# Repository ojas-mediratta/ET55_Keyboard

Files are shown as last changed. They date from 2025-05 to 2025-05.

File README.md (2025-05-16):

# ET55

## Overview

**ET55** is a 55‑key, hand‑wired mechanical keyboard created as the capstone project for **ECE 4180 – Embedded Systems Design** at Georgia Tech.  The goal was to design, fabricate, and program an ultra‑compact board that captures the feel of vintage IBM Model F layouts while showcasing modern embedded techniques—QMK firmware, USB‑C connectivity, an OLED status screen, and a rotary‑encoder volume knob.  All design files (schematic, PCB, plate, case, and firmware) are open‑sourced for anyone who wants to build or remix the board.

---

## Hardware

| Sub‑system | Details |
| --- | --- |
| **MCU** | Arduino Pro Micro / Bit‑C (ATmega32U4) with USB‑C connector |
| **Switch matrix**  | 55 MX‑compatible switches • Diode‑protected (COL2ROW) • NKRO enabled |
| **Keycaps** | Generic White on Black Keycaps |
| **Rotary encoder** | EC11 w/ integrated push‑button (used for volume + OLED mode cycling) |
| **OLED display** | 128×32 px SSD1306 module (I²C) for animations & system info |
| **Passives** | 1N4148 diodes (55×) • Reset capacitor & pull‑ups for I²C |
| **Power / I/O** | USB‑C for 5 V power & data |
| **Enclosure** | 3‑D printed case and switch plate (files included) |
| **Optional** | Surface‑mount ATmega32U4 variant for a future all‑in‑one PCB |

---

## Libraries & Code

ET55 runs stock **QMK** firmware (no custom forks), keeping the learning curve gentle for new contributors.

```bash
# Build the default keymap
qmk compile -kb et55 -km default

# Flash over USB (Pro Micro)
qmk flash -kb et55 -km default
```

* **Layers:** Base, Symbols, Nav, Function (configurable in `keymap.c`).
* **Encoder:** Volume up/down; press to cycle OLED screens.
* **OLED:** Bongo‑Cat animation + layer/status text (defined in `oled.c`).
* **Rules:** `rules.mk` enables LUFA, NKRO, OLED\_DRIVER, and ENCODER.

Feel free to fork and add combos, tap‑dance, or VIA support.

---

## Skills & Iteration

* **Schematic & PCB design** in KiCad; learned best‑practice matrix wiring and USB‑C routing.
* **Rapid prototyping:** 3‑D printed case revisions and laser‑cut plates ensured proper switch alignment before final print.
* **Hand‑wiring:** Applied heat‑shrink‑wrapped bus wires and diode‑legs to minimize shorts.
* **Firmware workflow:** QMK Configurator → local keymap → USB flashing & live debugging.
* **Peripheral integration:** Brought up I²C OLED on shared MCU pins, wrote basic frame‑buffer animations.
* **Documentation:** Maintained step‑by‑step build guide, BOM, and open‑sourced design files.

---

## Challenges

* **Tight matrix routing**—fitting 55 switches + diodes on a Pro Micro footprint required creative wire‑folds.
* **OLED noise**—solved flicker by adding 4.7 kΩ I²C pull‑ups and shielding SDA/SCL runs.
* **Encoder clearance**—first case revision fouled on encoder shaft; increased bezel height by 1 mm.
---

## Resources

* [QMK Docs](https://docs.qmk.fm/) – firmware reference & tutorials
* [nullbits Bit‑C](https://nullbits.co/bitc) – USB‑C Pro Micro replacement board
* [Hand‑Wired Guide](https://beta.docs.qmk.fm/tutorial/newbs_handwire) – official QMK hand‑wiring tutorial
* CAD, PCB, and firmware files are located in their respective folders in this repository—feel free to fork and improve.
---
## Photos and Videos

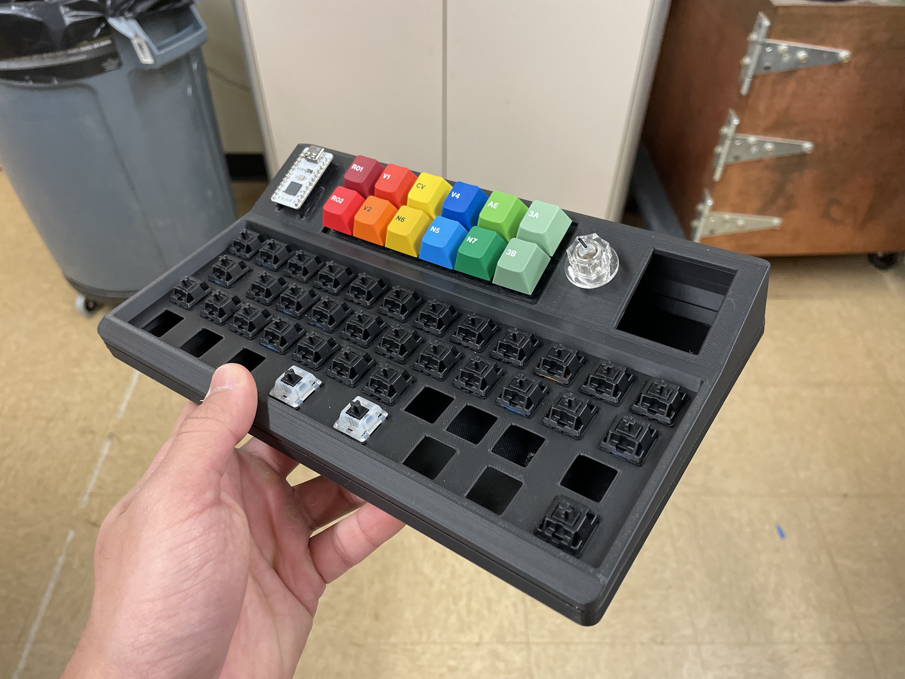
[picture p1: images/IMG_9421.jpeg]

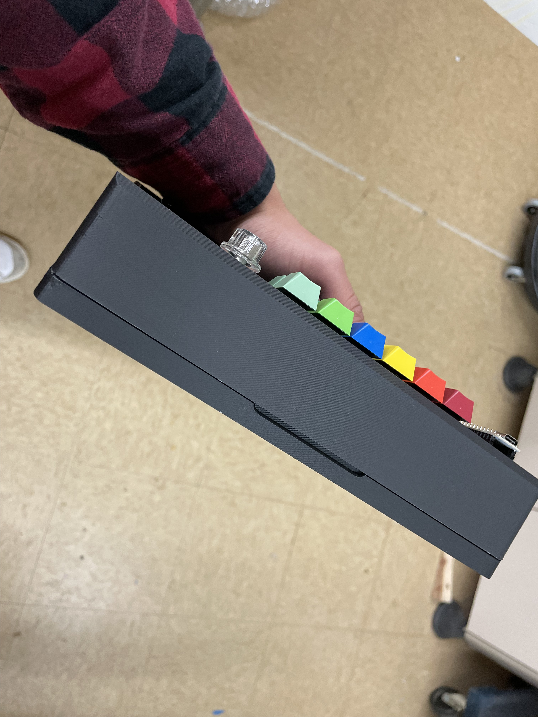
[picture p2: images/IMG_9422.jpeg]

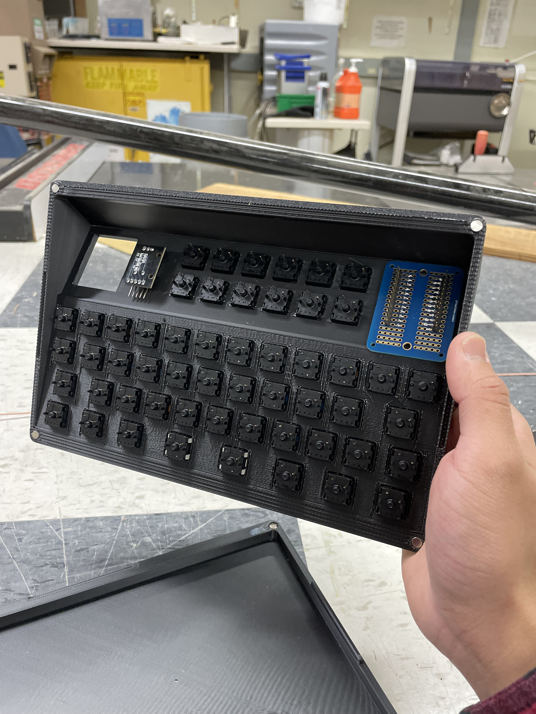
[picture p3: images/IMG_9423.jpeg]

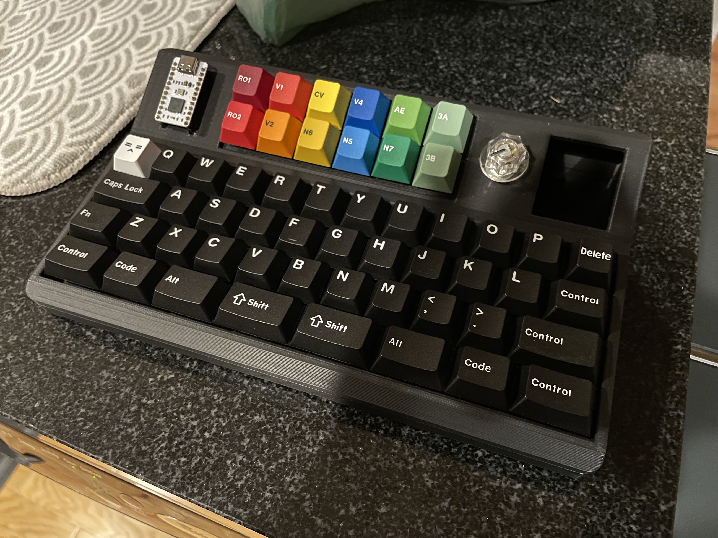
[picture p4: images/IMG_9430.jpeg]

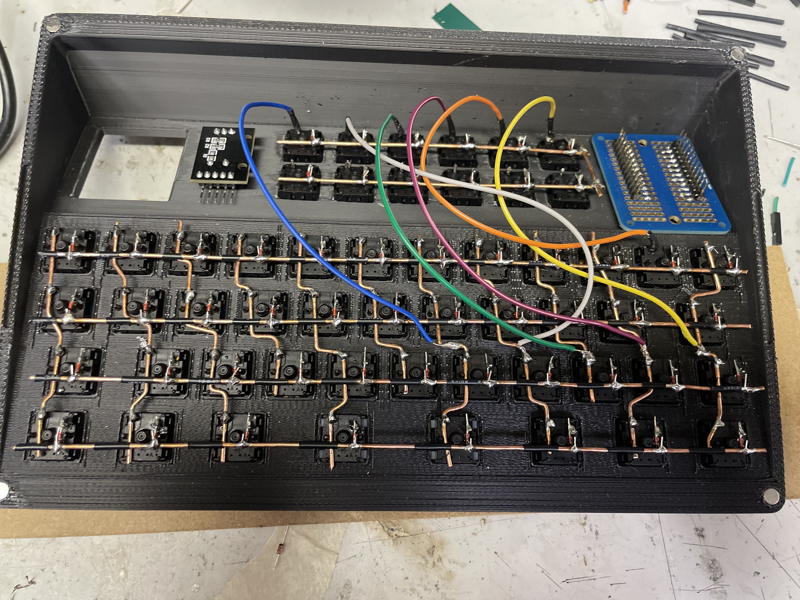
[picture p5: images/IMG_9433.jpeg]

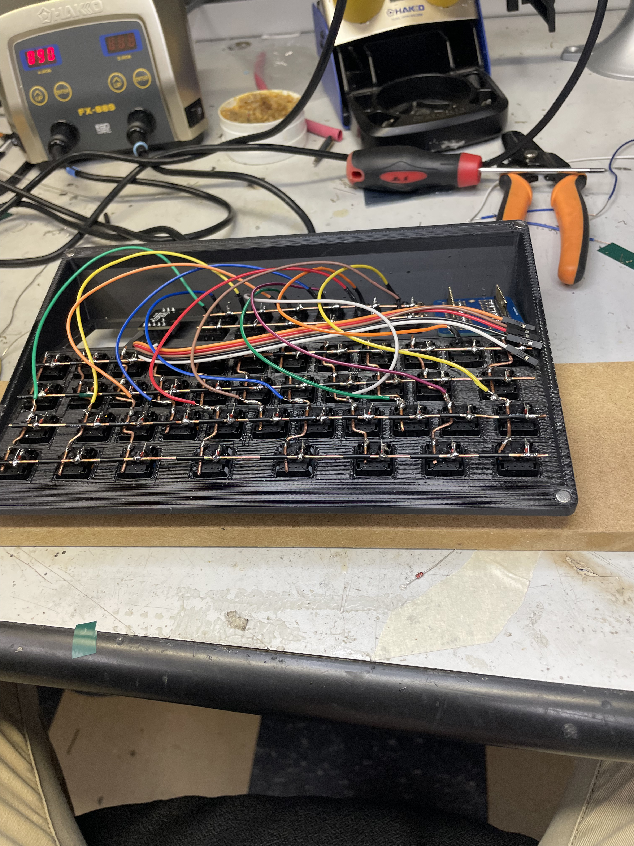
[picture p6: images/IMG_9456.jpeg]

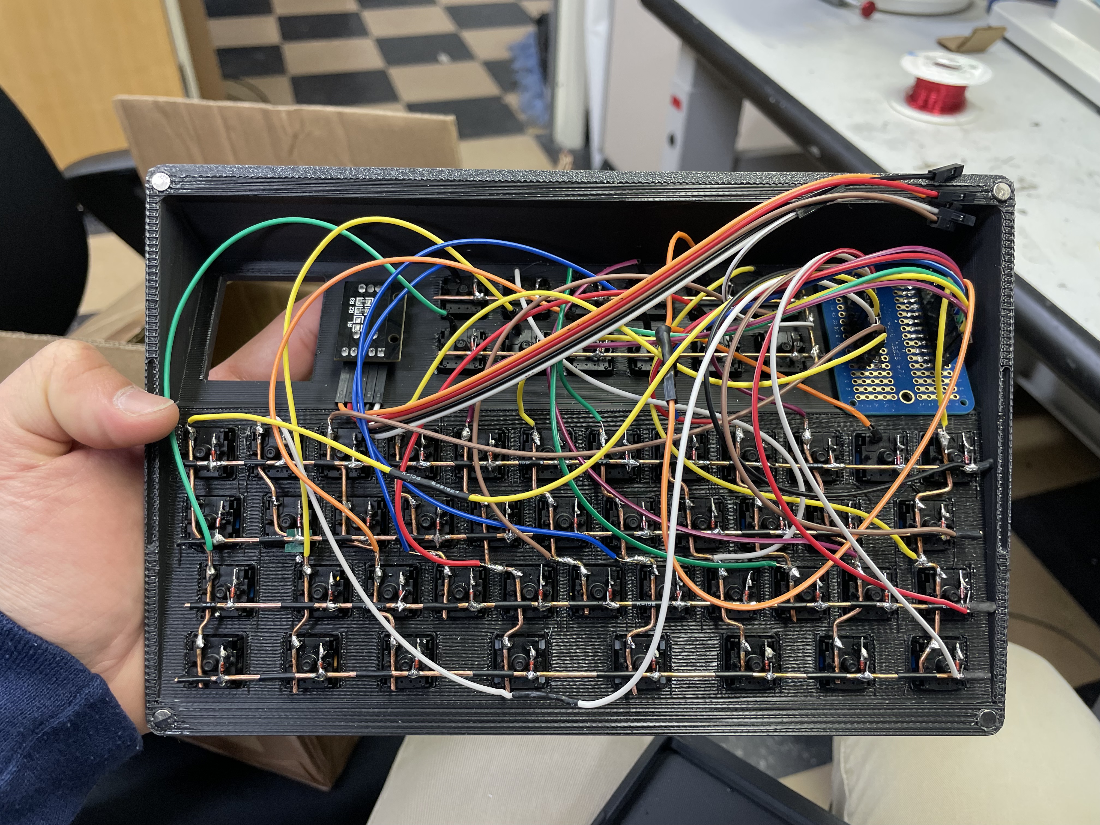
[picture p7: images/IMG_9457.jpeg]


*Project by **Ojas Mediratta**, Fall 2024 – Georgia Institute of Technology, ECE 4180.*

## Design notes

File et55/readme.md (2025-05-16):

# handwired/et55

handwired/et55

*A short description of the keyboard/project*

* Keyboard Maintainer: [Ojas Mediratta](https://github.com/ojas-mediratta)
* Hardware Supported: *The PCBs, controllers supported*
* Hardware Availability: *Links to where you can find this hardware*

Make example for this keyboard (after setting up your build environment):

    make handwired/et55:default

Flashing example for this keyboard:

    make handwired/et55:default:flash

See the [build environment setup](https://docs.qmk.fm/#/getting_started_build_tools) and the [make instructions](https://docs.qmk.fm/#/getting_started_make_guide) for more information. Brand new to QMK? Start with our [Complete Newbs Guide](https://docs.qmk.fm/#/newbs).

## Bootloader

Enter the bootloader in 3 ways:

* **Bootmagic reset**: Hold down the key at (0,0) in the matrix (usually the top left key or Escape) and plug in the keyboard
* **Physical reset button**: Briefly press the button on the back of the PCB - some may have pads you must short instead
* **Keycode in layout**: Press the key mapped to `QK_BOOT` if it is available

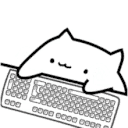
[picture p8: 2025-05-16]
images/frames/frame_1_delay-0.1s.gif

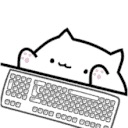
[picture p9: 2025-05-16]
images/bongo-cat-idle.jpeg

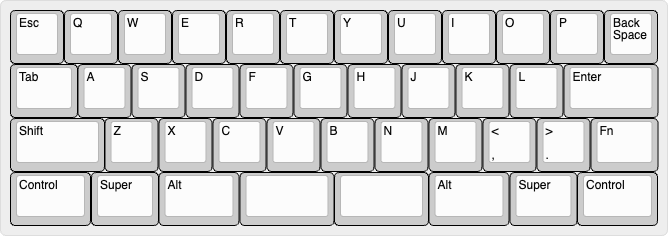
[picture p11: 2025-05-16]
Plate_Layout/40-modified.png

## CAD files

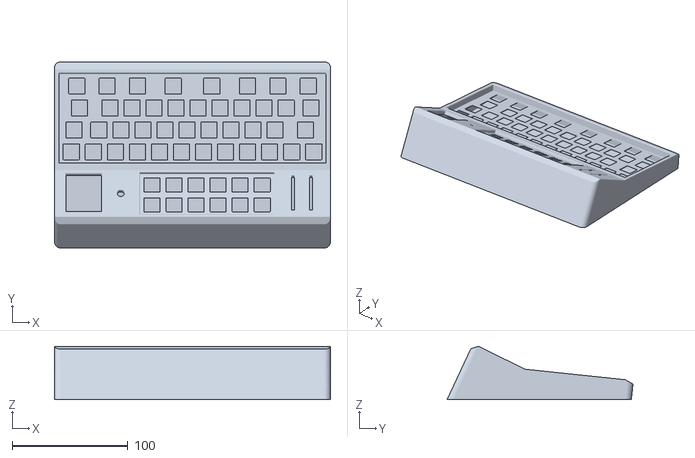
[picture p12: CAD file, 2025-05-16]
Based Board.stl
238.6 x 160.8 x 46.1

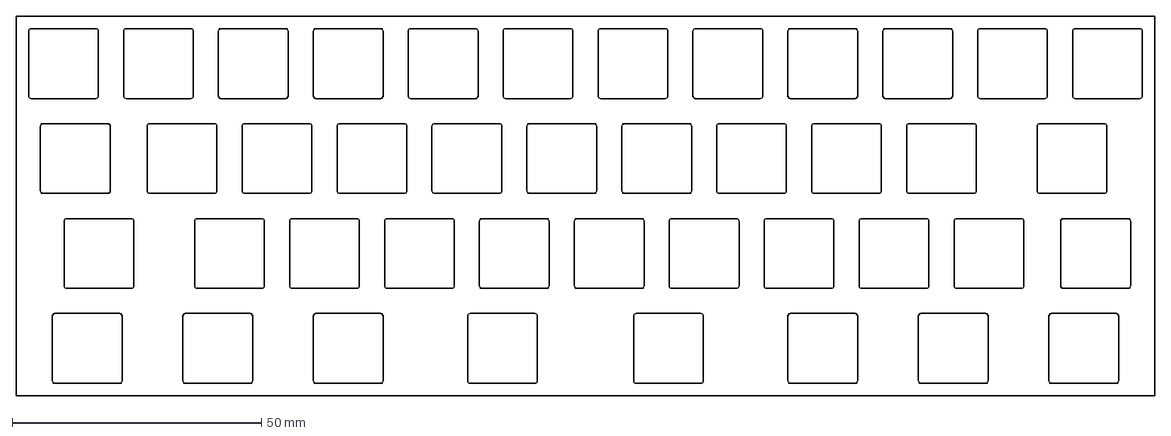
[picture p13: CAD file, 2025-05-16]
Plate_Layout/plate-2024-11-20T15_15_17.949Z.dxf
228.6 x 76.2 mm

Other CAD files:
Based Board XL.stl
Based Board XL.f3d
Based Board.f3d

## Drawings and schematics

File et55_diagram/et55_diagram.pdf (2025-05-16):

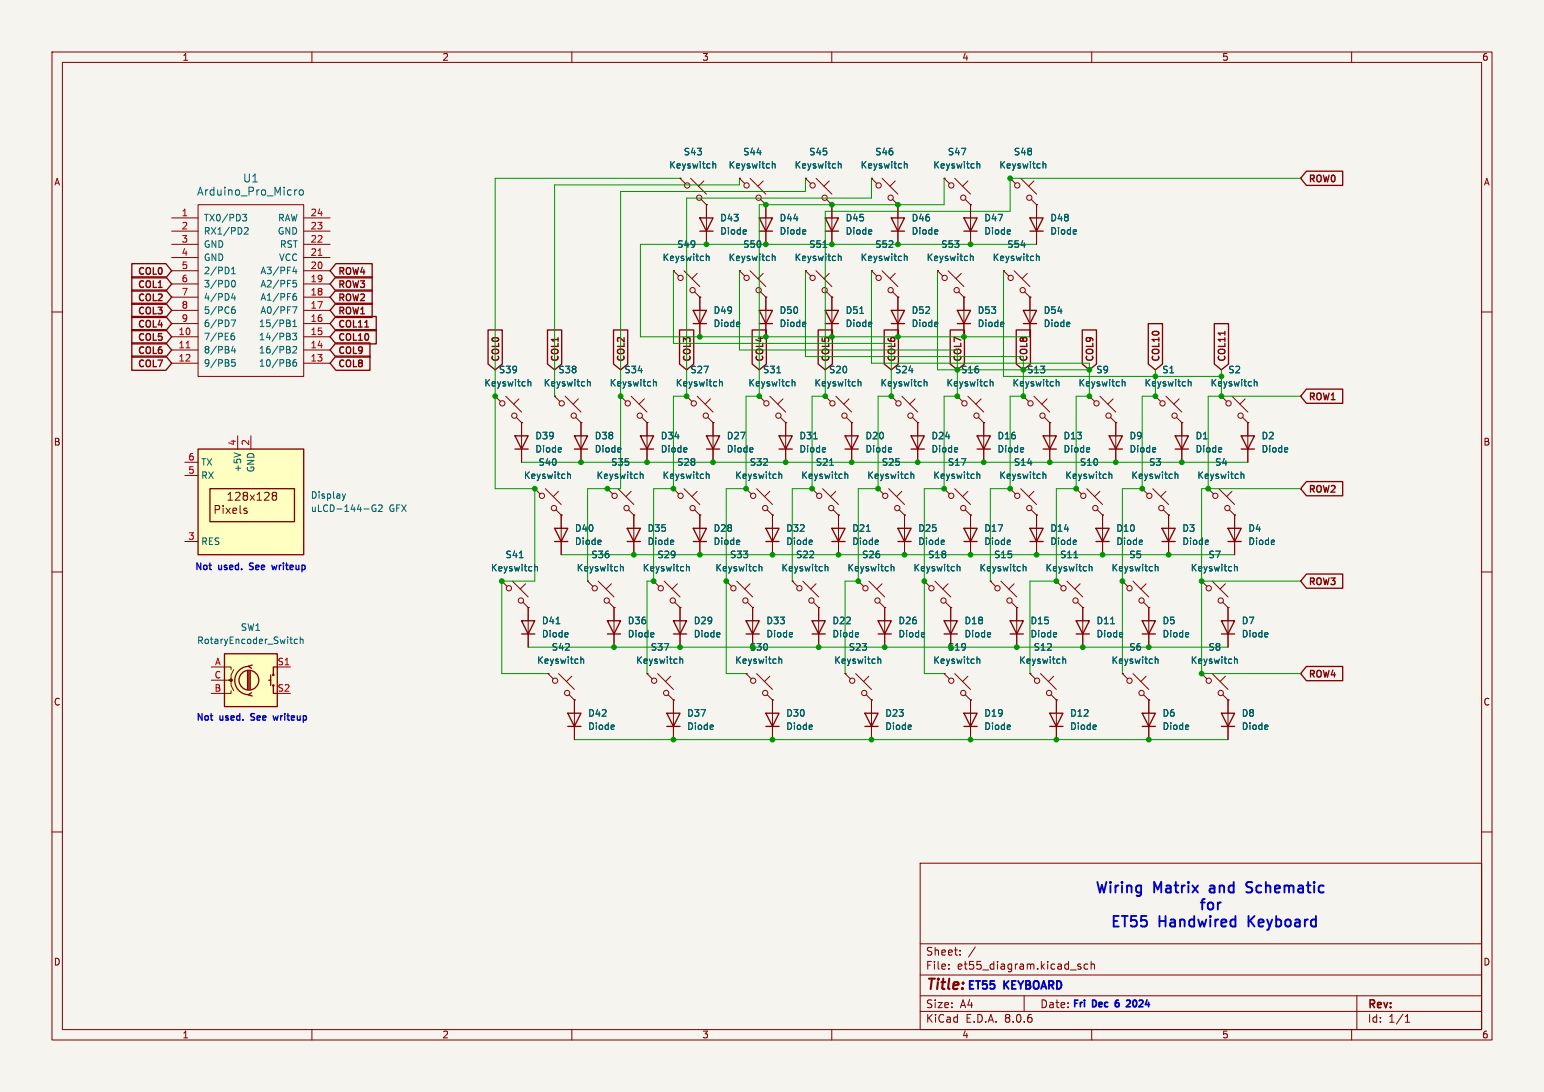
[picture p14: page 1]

4 RX 5 TX 6 Display uLCD-144-G2 GFX

Not used. See writeup

Wiring Matrix and Schematic
